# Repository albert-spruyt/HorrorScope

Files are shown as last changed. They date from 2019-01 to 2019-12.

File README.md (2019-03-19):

# HorrorScope / ScaCheapier

This repository contains all the firmware source, scripts and notebooks for the ScaCheapier workshop given at 35c3. 

We gave a talk about this work at Troopers 2019 NGI, with a different perspective. You can find the slides in the presentation directory.

## Abstract 
From: https://events.ccc.de/congress/2018/wiki/index.php/Session:ScaCheapier

Want to recover cryptographic keys by just looking at a chip's power usage, for the price of a few beers?

In this workshop we will show you how to break AES with just ~5 euro of equipment (plus your laptop and a bit of code).

Following in the tradition of the ChipWhisperer, but with even cheaper hardware, come and join the world of hardware side channel attacks. With a simple custom PCB (schematics provided), a cheap off-the-shelf MCU and a handful of supporting components, you'll have no problem stealing the keys. 

## Presentation

During the workshop we partially re-used a presentation created by Ilya Kizhvatov. The original slides can be found here:  
https://www.slideshare.net/phdays/ss-35302416  
A recording of Ilya himself giving the talk can be found here: https://vimeo.com/100108647  

If you saw our talk at Troopers, you missed out on all the theory; you can watch Ilya's presentation to get it!

## Code repository

The code in the repository, in particular the FI and Scope FW parts, should be considered PoC code. In fact, don't take anything here too seriously. Have fun!

The repository is organized as follows:

Scope   - Scope and Glitcher Firmware (firmware in lufa\*/Projects/HorrorScope  
Acq     - Python acquisition scripts including the Scope GUI  
FI      - Python FI scripts/ including plotting  
julia   - The julia jupyter notebook  
presentation - The presentation for the workshop (and the troopers talk) 
PCB     - PCB files  

#### Patched LUFA
The Scope folder contains an entire copy of LUFA http://fourwalledcubicle.com/LUFA.php  

To maximize the amount of SRAM available as sample memory LUFA has been patched to minimize the number and size of USB buffers.   

The patch has been applied in Drivers/USB/Core/XMEGA/Endpoint_XMEGA.h  

## Installation

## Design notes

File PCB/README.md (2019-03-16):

# HorrorScope PCB design

These are the kicad source files for our 'horrorscope' PCB. You can find gerbers in the 'horrorscope' directory.

(The 'breakout' directory contains gerbers for the breakout PCB we developed for debugging, which may be interesting too.)

Obviously .. we are not electrical engineers. Or good at PCB design. But it works! :)

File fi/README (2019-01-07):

#ONELINERS FTW
./parseLog.py log.log | sort -n | grep ' 4$' | awk {'print $3'} | sort -u | wc
-l # How many uniq faults do i have?
# extract faults for jean gray, you have to add the correct response to the
top
./parseLog.py log.log | sort -n | grep ' 4$' | awk {'print $3 " " $3'} | sort -u > JeanGrey-master/tracefile

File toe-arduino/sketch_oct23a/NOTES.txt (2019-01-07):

USES AESLIB from:
    https://github.com/DavyLandman/AESLib
Clone and move into ~/Arduino/libraries
And name the folder AESLib

Encrypt command has the format: 'a' + 16 bytes input data + '\n

Preparing the board:
    - Program board and verify functioning.
    - Cut next to the diode -> plug into USB -> power led shouldn't turn on
    - Cut next to the last pin of the USB chip
    - Solder diode (side with the cut) to pwr 5v (First put in a pin, solder to bottom of pin)

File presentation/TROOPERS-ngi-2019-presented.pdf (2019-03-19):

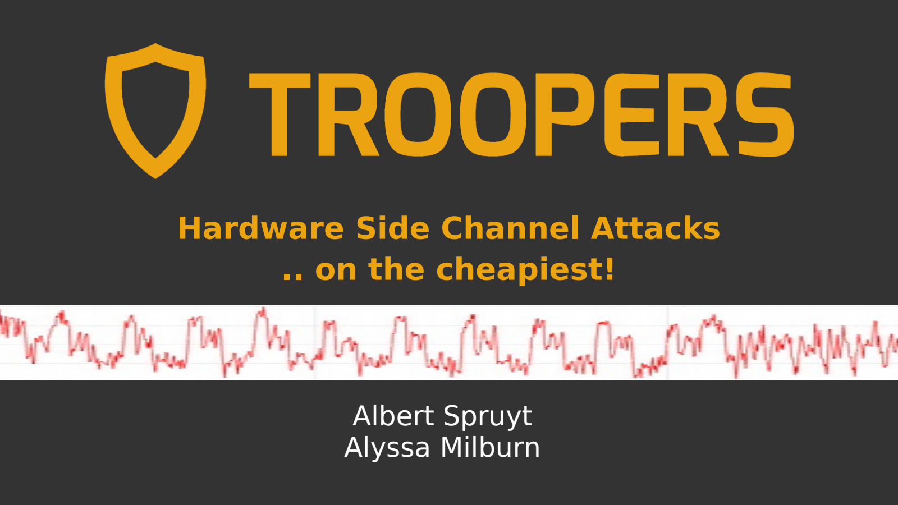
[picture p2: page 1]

Hardware Side Channel Attacks .. on the cheapiest!

Albert Spruyt
Alyssa Milburn

2

About Us

## Alyssa

PhD student

@noopwafel

## Albert

Unemployed

3

Today

## - Side Channel Analysis - (Cheap) Hardware - Demos! - A bit of Fault Injection

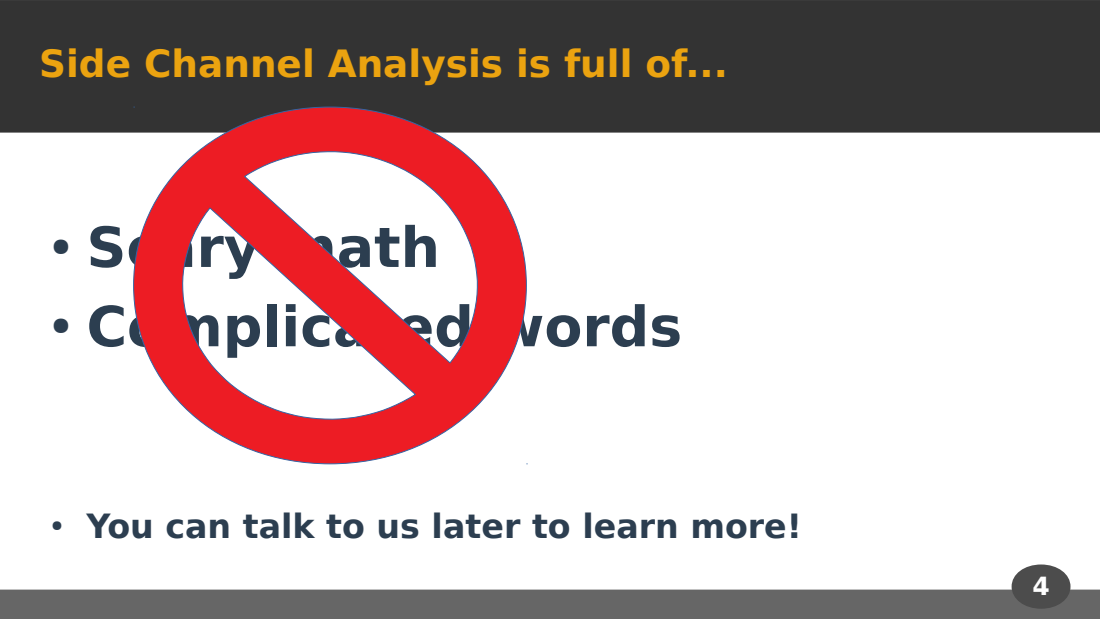
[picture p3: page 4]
● Scary math ● Complicated words

Side Channel Analysis is full of...

● You can talk to us later to learn more!

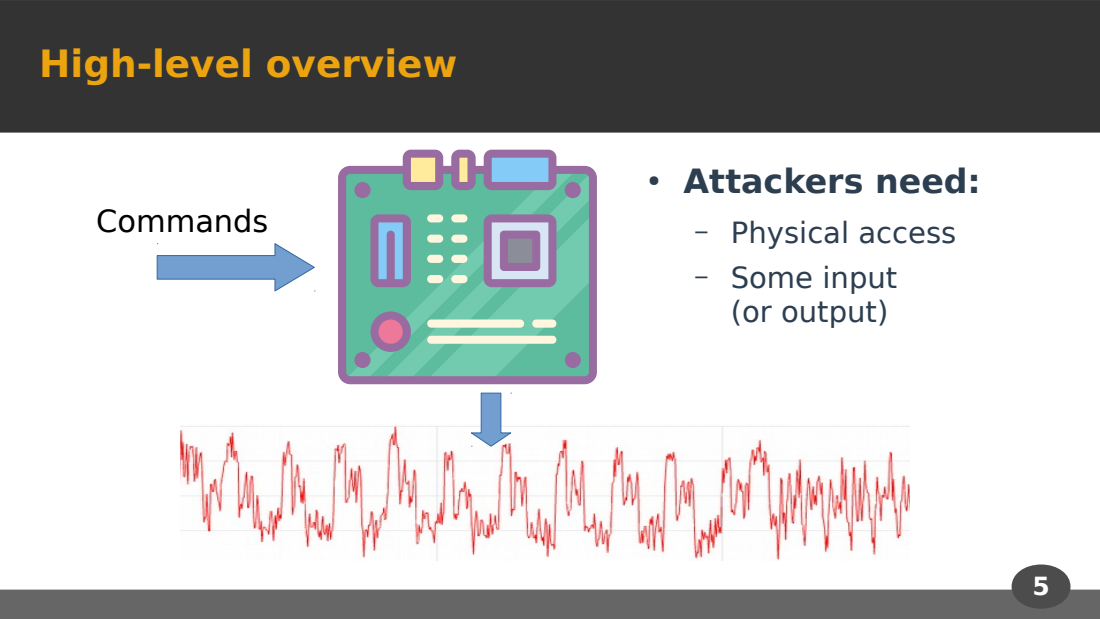
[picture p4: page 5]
Commands; ● Attackers need:; – Physical access – Some input (or output)

High-level overview

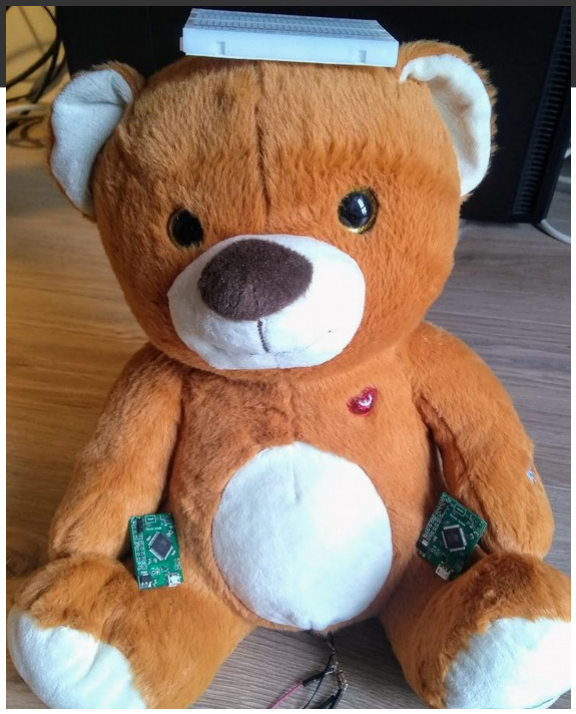
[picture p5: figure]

6

The context

- Smartcards
– credit cards, access cards, passports
- Secure microcontrollers
– crypto wallets, U2F/YubiKey
- Random IoT devices
– lightbulbs, ...

## Why care about side channels?

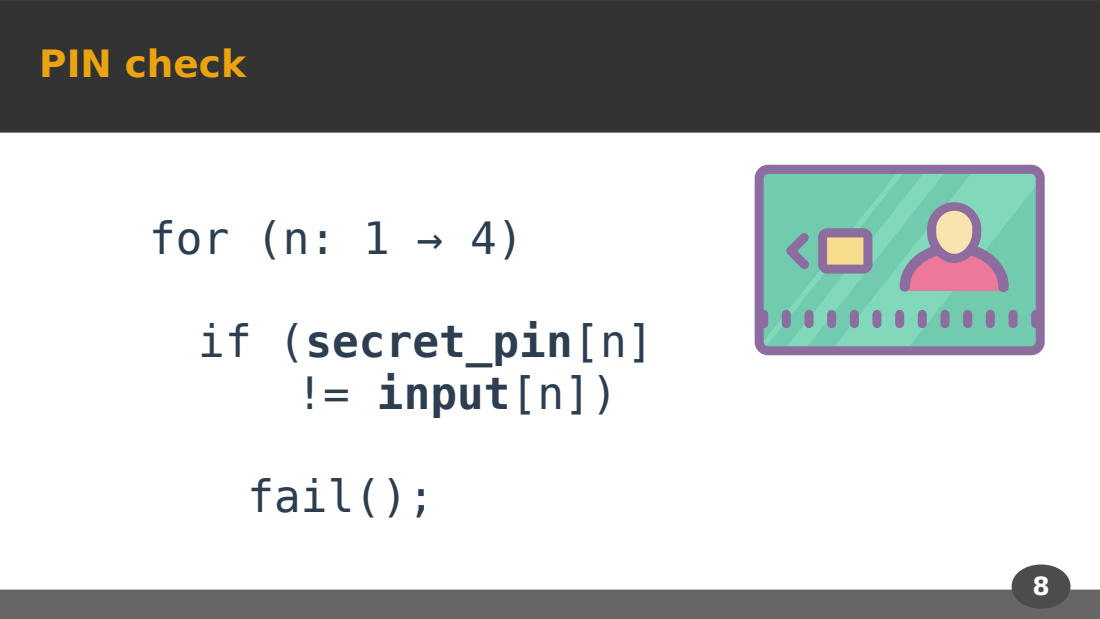
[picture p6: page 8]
PIN check; for (n: 1 → 4); if (secret_pin[n] != input[n]); fail();

9

PIN check

## if (secret_pin[n] != input[n])

fail();

10

PIN check

n=1

n=1 and n=2

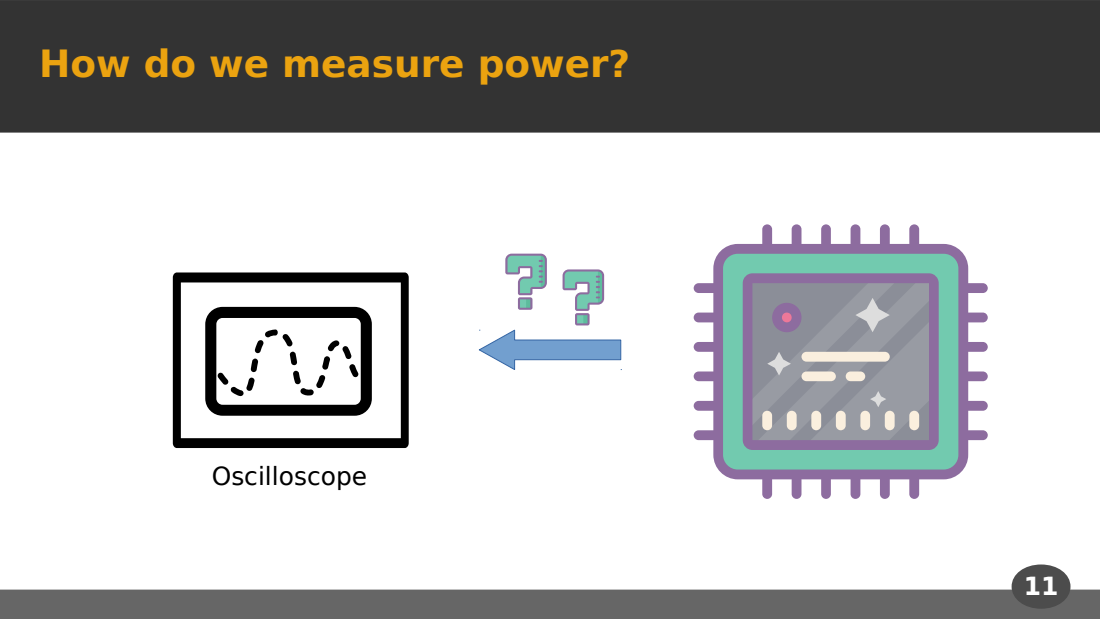
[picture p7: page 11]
Oscilloscope

How do we measure power?

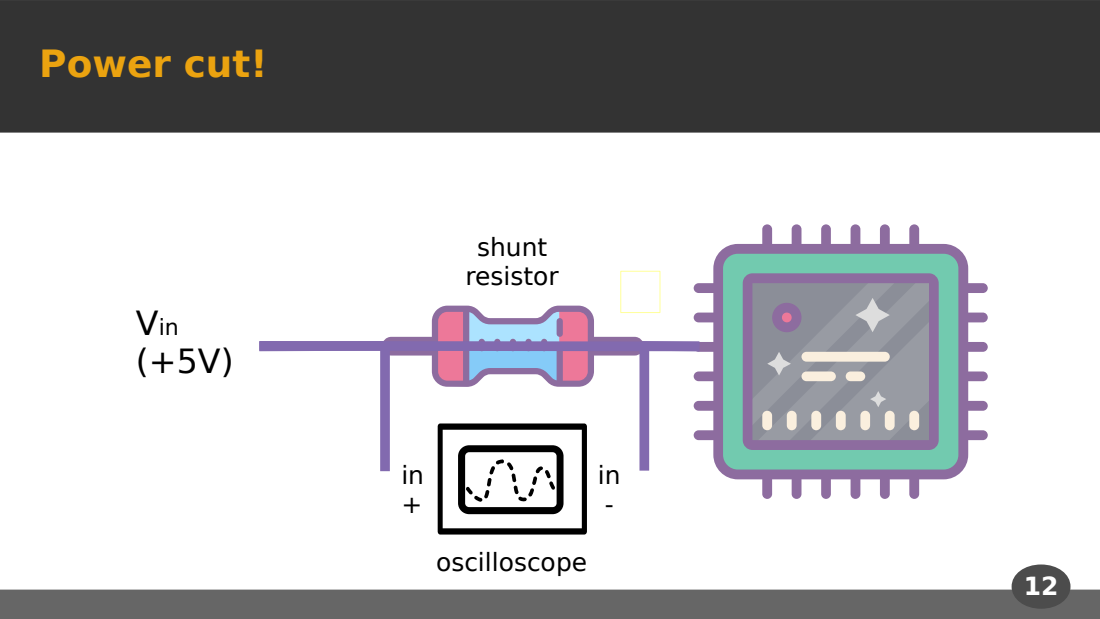
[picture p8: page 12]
Power cut!; Vin (+5V); shunt resistor; oscilloscope

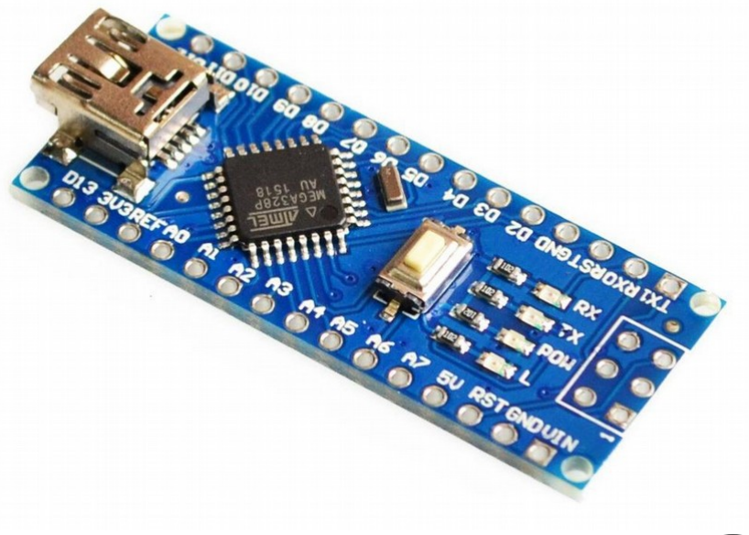
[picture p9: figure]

13

Today’s target

Arduino Nano

- 16 Mhz
- ~3-5 euro
- Not secure

14

Real power cuts

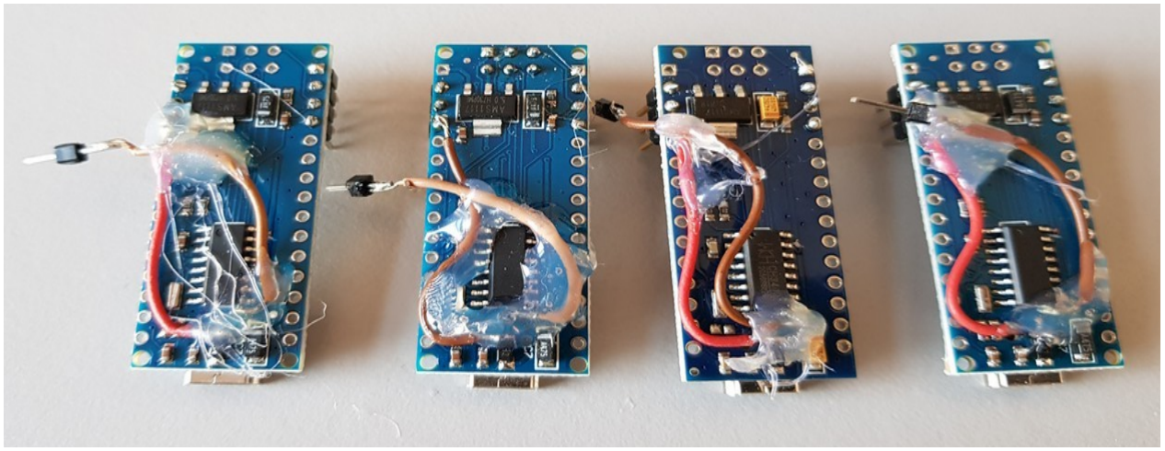
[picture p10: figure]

15

Real power cuts

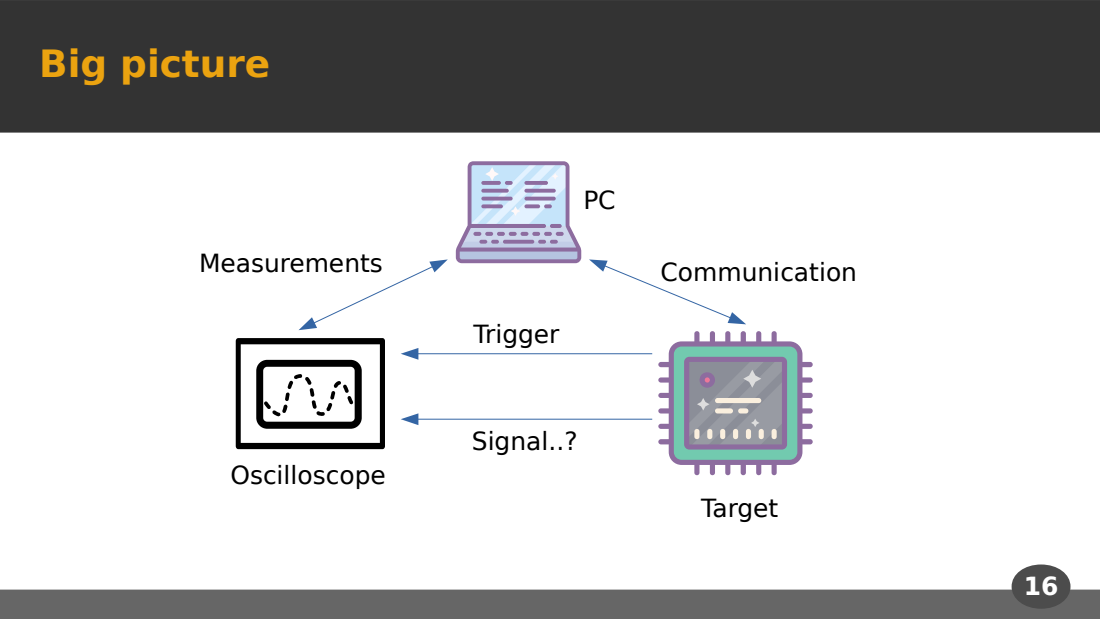
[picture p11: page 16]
Big picture; Measurements; Communication; Trigger; Signal..?; Oscilloscope; Target

17

DEMO

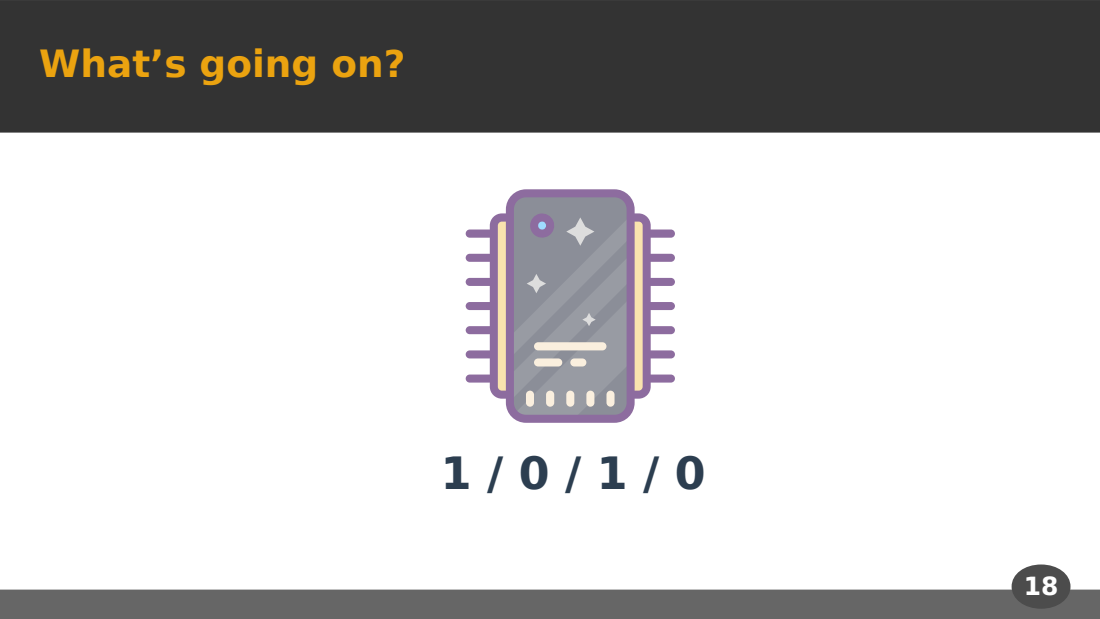
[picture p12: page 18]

What’s going on?

19

Hamming weight

0x00: 00000000
→ hamming weight 0

0xFF: 11111111
→ hamming weight 8

0x05: 00000101
→ hamming weight 2

0x11: 00010001
→ hamming weight 2

20

Leakage?

- Calculate with (random) bytes
- Take power traces

Can we match the Hamming Weight of the byte to the power traces?

21

Hamming weight

- Power profiles
based on different
data
- Averaged
- We can see the data
being processed!

Source: Side channel analysis, practice and a bit of theory. Ilya Kizhvatov

23

Keys

- We’re going to steal encryption keys – Everyone needs to have keys

24

Super secure encryption

- AES-128: unbroken and secure

Input

Initial ro

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
al R

o
u
n
d

Output

25

AES trace

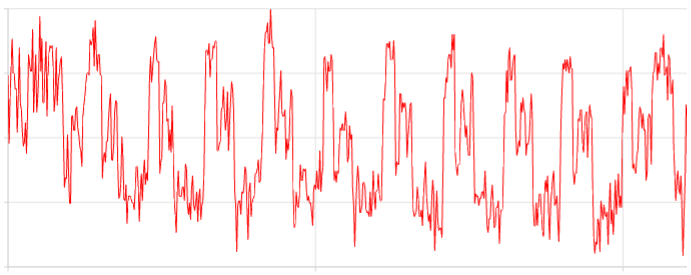
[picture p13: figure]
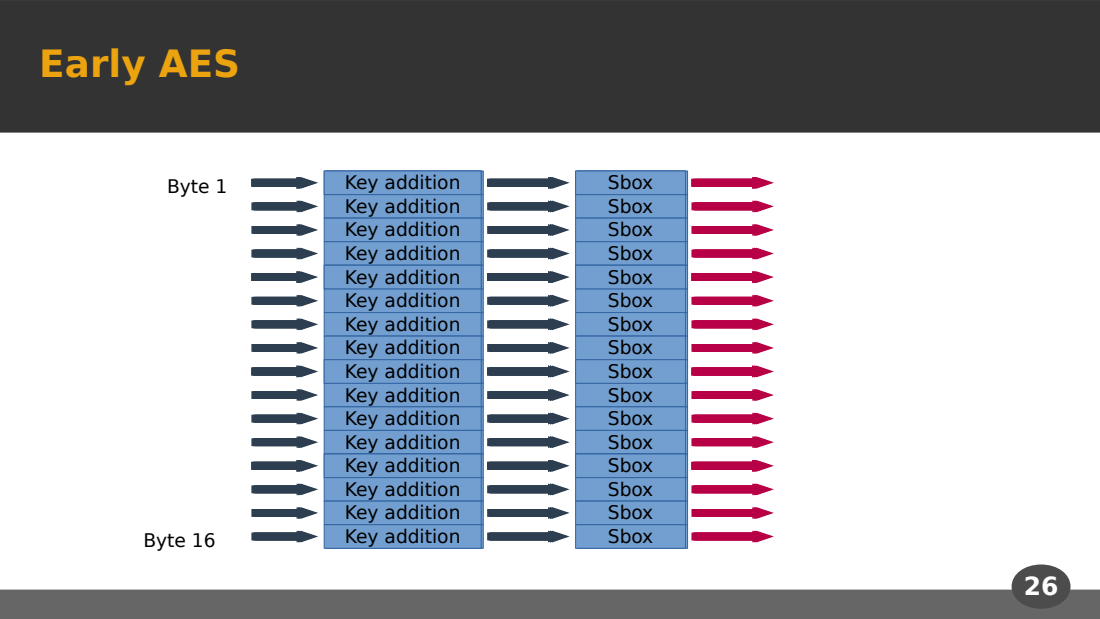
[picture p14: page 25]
Early AES; Key addition; Sbox; Byte 1; Byte 16

27

Single byte only

- We can look at each byte separately!

Key Addition; Input byte; Sbox; Key byte

28

Single byte only

- Only 256 possible key bytes – Try them all!

Key Addition; Input byte; Sbox; Key; byte; Hamming weight?

29

The master plan

- For every key guess:
– For each input:
- Calculate Hamming Weight after the S-box
- Compare that with the actual leakage
- Pick the guess with the best fit!

30

## Correlation Power Analysis

32

We’re lazy!

- Open source: JLSCA
– Does CPA for us
– Also supports fancier attacks – Runs fast on a cheap laptop

(Thanks Cees!)

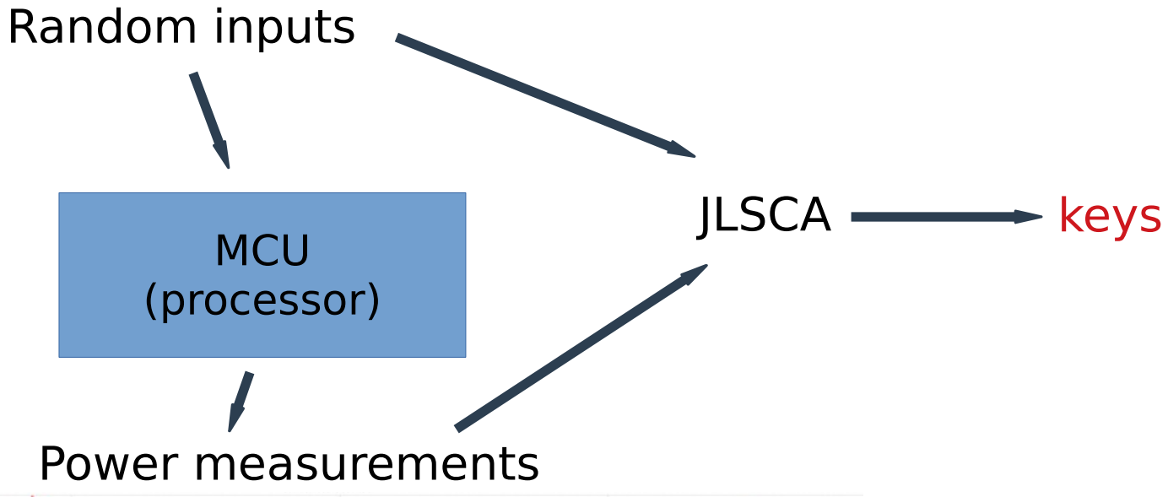
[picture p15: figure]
MCU (processor); Random inputs; Power measurements; JLSCA; keys

33

New plan

34

Oscilloscope?

35

Oscilloscopes

LeCroy WaveRunner | $17 000
PicoScope 3406D | $2 500
Rigol DS1054Z | $500

36

Previous Work

ChipWhisperer | $250
Hantek USB oscilloscope | $60
ChipWhisperer Nano..? | $50

ChipWhisperer
Nano

39

Solving our hardware woes

Let’s build an awesome, cheap scope!

Let’s hack something together!

40

What do we need?

- GPIO to trigger
- ADC to measure
- Memory to store measurements

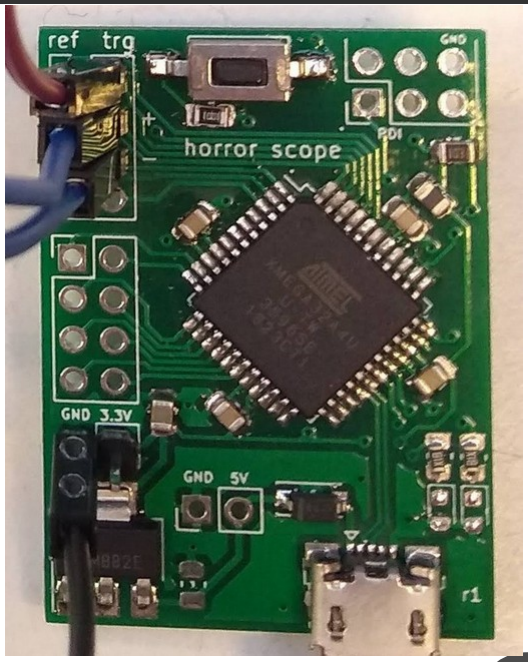
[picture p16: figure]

41

HorrorScope

Atmel XMEGA
– USB 2.0
– 12-bit ADC @2 MSPS

42

Bill of Materials (BOM)

~5 euro ex. VAT

Xmega: | 2.50eur
PCB: | 1eur

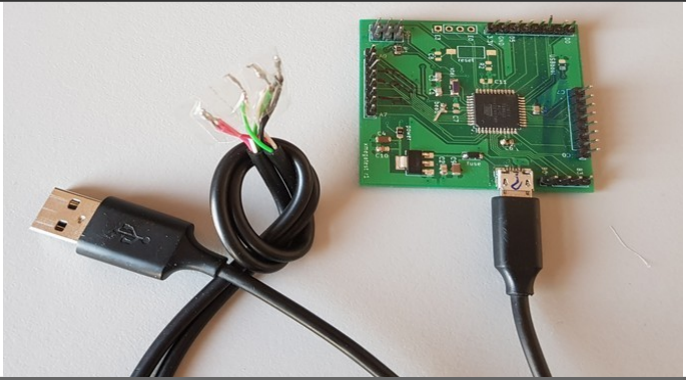
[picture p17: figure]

43

Funny story 1

44

More problems
Design considerations

Sampling below Nyqist frequency

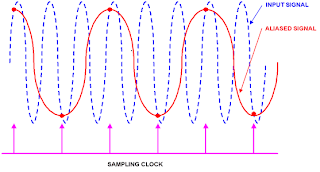
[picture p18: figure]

Source: http://blog.teledynelecroy.com/2013/06/back-to-basics-sampling-rate.html

Nano: | 16Mhz
Our ADC: | 2Mhz

45

Xmega datasheet

- Just a suggestion

46

More problems
Design considerations

No analog front-end

DC offset, resolution, noise, ... – AC coupling, use AREF

47

Funny story 2

Coding is hard

48

More traces!

100 traces averaged: A wild AES appears!

49

Acquisition

●

## So: let’s try it!

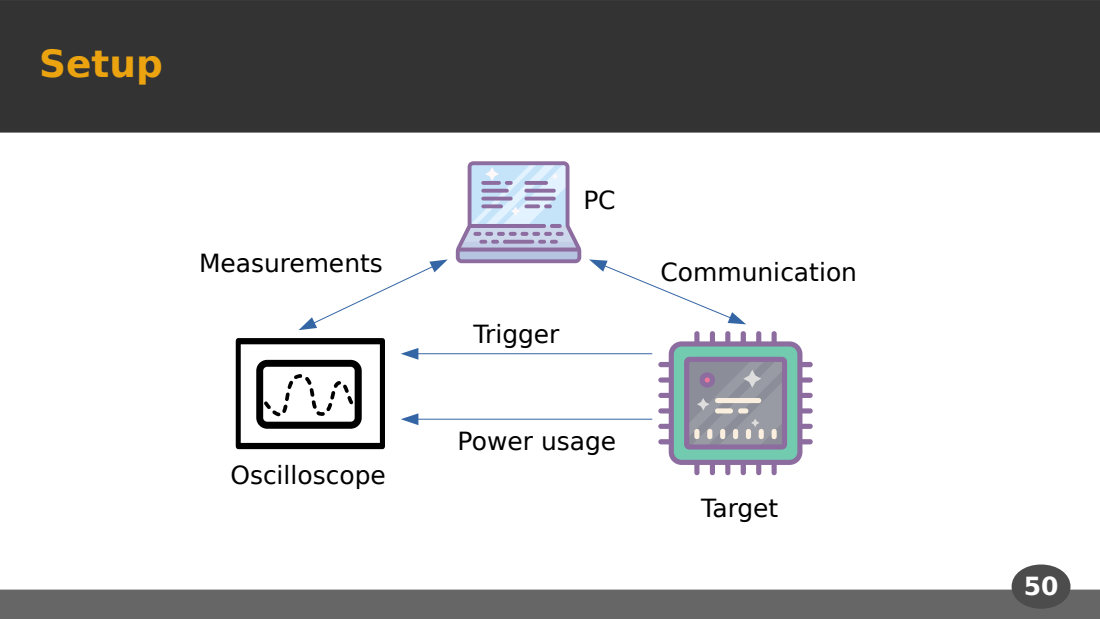
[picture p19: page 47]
Setup; Measurements; Communication; Trigger; Power usage; Oscilloscope; Target

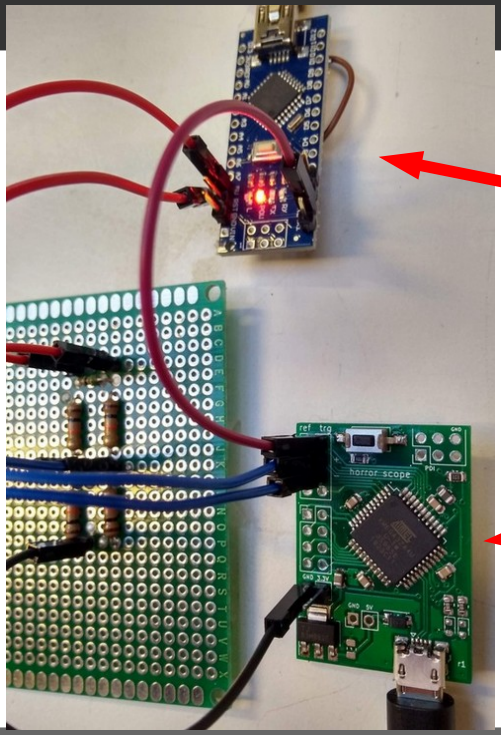
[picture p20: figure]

52

Real world setup

We have:
“Target”:
Arduino Nano + AES

“Oscilloscope”:
HorrorScope

53

Triggering

How does the scope know when to measure? – Not enough SRAM to sample all the time
– We need to sync the scope to the target

So, whats the last thing we control? – Sending the input

54

Triggering plan

- HorrorScope measuring procedure – Send command to Scope (arm)
– GPIO pin turns high
– Actually start measuring

– Connect Scope GPIO pin to RX on Nano

55

When to start measuring …

Time

Start

Send input
Arm scope

Send last input byte
Scope triggers
Target does AES
Save data +
power trace

56

Collect traces...

We need a lot of traces
– Make sure the first/or last round is in view – Select a high Sample speed
- Ensure there’s a margin before/after the round

57

Take Traces

- AES: initial round, 9 rounds, a final round

58

Acquiring Traces …

…. Here’s one we made earlier

59

Traces are bad

- Why are they bad?

60

What’s wrong?

- Misalignment

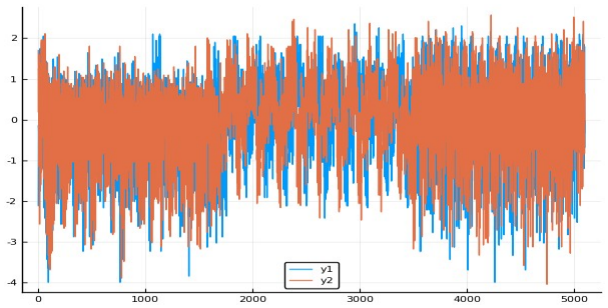
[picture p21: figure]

61

Signal spread

Source: Side channel analysis, practice and a bit of theory. Ilya Kizhvatov

62

Aligned

Aligned Not aligned!

Thank you JLSCA!

63

Why is alignment important?

Before | after

64

Let’s get keys

- DEMO
– Jupyter notebook

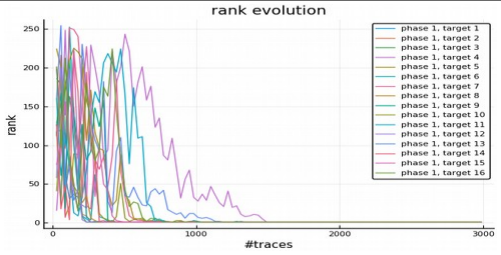
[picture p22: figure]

66

Comparing the scopes

Vds1022 ($70):
~1.5k traces

HorrorScope:

~30k traces

67

Funny Story 3

- How many mistakes can we make before it doesnt work?
- Silkscreen-Off-By-One

68

Funny story 3

- People told us the Xmega ADC was bad

69

Funny story 3

- 1000 averaged, no alignment

70

Strength in numbers

- Side Channel Attacks require overcoming the noise
- Noise can be reduced through taking more traces, but not in every case

71

Fault Injection

HorrorScope can sort of power the Nano

- The Nano wants 5v
- Xmega GPIO pins provide 3.2v

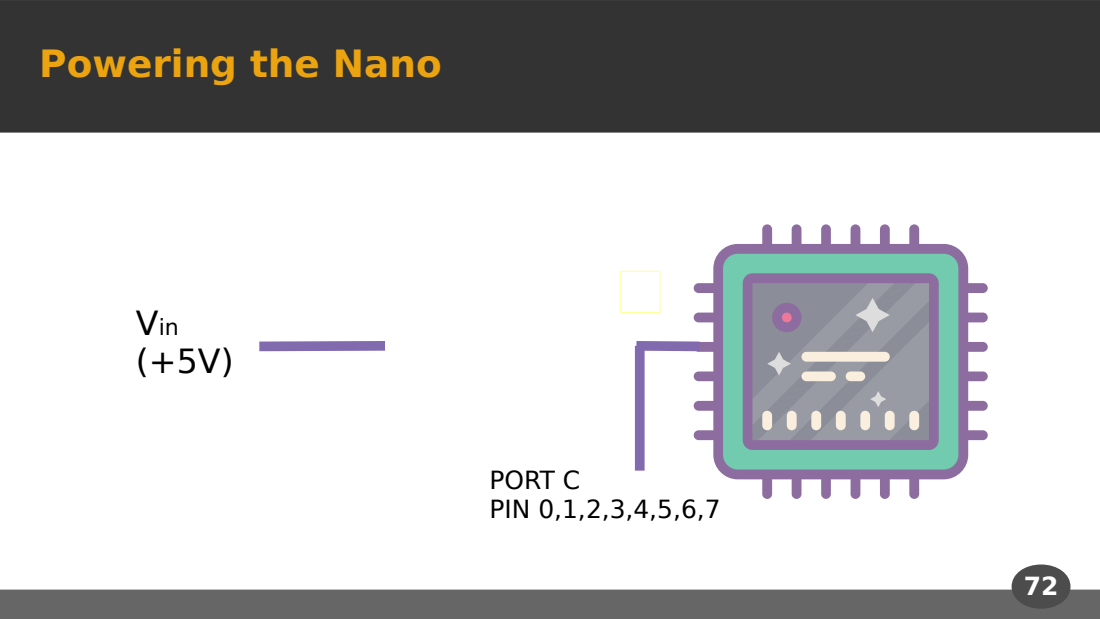
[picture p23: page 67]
Vin (+5V); PORT C PIN 0,1,2,3,4,5,6,7

Powering the Nano

73

Ok faults, now what?

- Perform Fault Injection and Differential Fault Analysis
- Inject faults into AES and recover the key

74

What can you do about it?

- Threat model
– Do you need to resist physical attacks? Best defense: make sure it doesn’t matter!
- Basic steps
– Use hardware with built-in countermeasures .. and check it with a (Horror)scope :)
(or a ChipWhisperer)!

75

Conclusion

- Hardware attacks are cheaper than we thought
- Side Channel Analysis is something you can do at home – and you should try it

76

Special Thanks

- Cees-Bart ‘ceesb’ Breunesse – https://github.com/Riscure/Jlsca
- Rafa Boix Carpi
– For saying it can’t be done
- Ilya Kizhvatov
– Letting us steal his pictures
- Workshop attendees
– For their feedback and love

77

Homework

https://github.com/albert-spruyt/HorrorScope/

Provided: power traces and Jlsca notebook. You should now be able to get the key!

(Also in the repo: schematics/source/etc) .. we’re hoping for a port to the STM32 – SCA for $2?

78

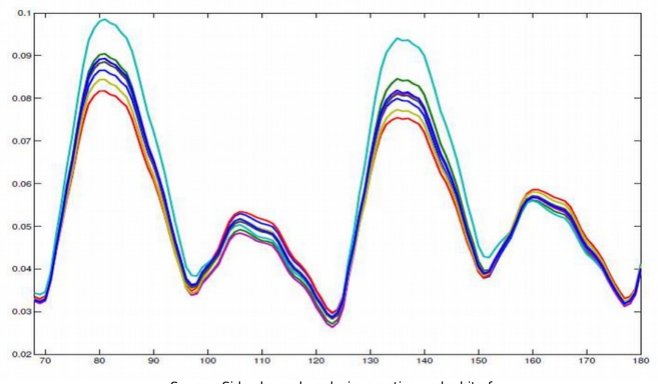
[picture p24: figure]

79

Hamming weight

- Power profiles
based on different
data
- Averaged
- We can see the data
being processed!

Source: Side channel analysis, practice and a bit of theory. Ilya Kizhvatov

80

Power cut: easy?

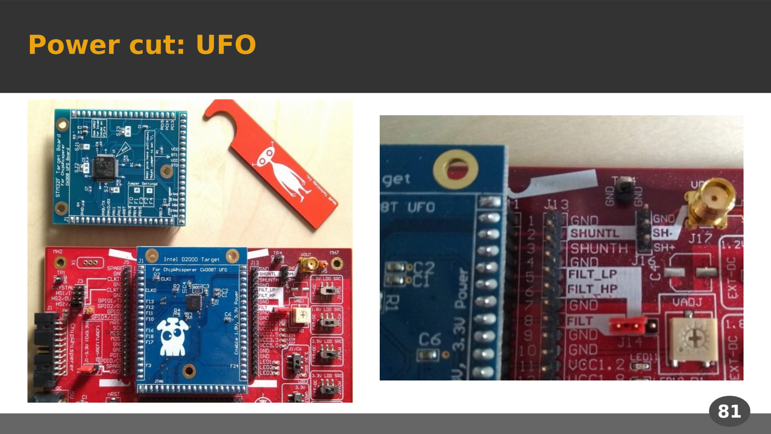
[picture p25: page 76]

81

Power cut: UFO

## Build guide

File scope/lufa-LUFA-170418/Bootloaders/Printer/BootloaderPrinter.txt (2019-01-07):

/** \file
 *
 *  This file contains special DoxyGen information for the generation of the main page and other special
 *  documentation pages. It is not a project source file.
 */

/** \mainpage Printer Class USB AVR Bootloader
 *
 *  \section Sec_Compat Demo Compatibility:
 *
 *  The following list indicates what microcontrollers are compatible with this demo.
 *
 *  \li Series 7 USB AVRs (AT90USBxxx7)
 *  \li Series 6 USB AVRs (AT90USBxxx6)
 *  \li Series 4 USB AVRs (ATMEGAxxU4)
 *  \li Series 2 USB AVRs (AT90USBxx2, ATMEGAxxU2)
 *
 *  \section Sec_Info USB Information:
 *
 *  The following table gives a rundown of the USB utilization of this demo.
 *
 *  <table>
 *   <tr>
 *    <td><b>USB Mode:</b></td>
 *    <td>Device</td>
 *   </tr>
 *   <tr>
 *    <td><b>USB Class:</b></td>
 *    <td>Printer Class</td>
 *   </tr>
 *   <tr>
 *    <td><b>USB Subclass:</b></td>
 *    <td>Printer Subclass</td>
 *   </tr>
 *   <tr>
 *    <td><b>Relevant Standards:</b></td>
 *    <td>USBIF Printer Class Standard</td>
 *   </tr>
 *   <tr>
 *    <td><b>Supported USB Speeds:</b></td>
 *    <td>Full Speed Mode</td>
 *   </tr>
 *  </table>
 *
 *  \section Sec_Description Project Description:
 *
 *  This bootloader enumerates to the host as a Generic Text Only Printer device, capable of reading and parsing
 *  "printed" plain-text Intel HEX files to load firmware onto the AVR.
 *
 *  Out of the box this bootloader builds for the AT90USB1287 with an 8KB bootloader section size, and will fit
 *  into 4KB of bootloader space. If you wish to alter this size and/or change the AVR model, you will need to
 *  edit the MCU, FLASH_SIZE_KB and BOOT_SECTION_SIZE_KB values in the accompanying makefile.
 *
 *  When the bootloader is running, the board's LED(s) will flash at regular intervals to distinguish the
 *  bootloader from the normal user application.
 *
 *  \section Sec_Running Running the Bootloader
 *
 *  On the USB AVR8 devices, setting the \c HWBE device fuse will cause the bootloader to run if the \c HWB pin of
 *  the AVR is grounded when the device is reset.
 *
 *  The are two behaviours of this bootloader, depending on the device's fuses:
 *
 *  <b>If the device's BOOTRST fuse is set</b>, the bootloader will run any time the system is reset from
 *  the external reset pin, unless no valid user application has been loaded. To initiate the bootloader, the
 *  device's external reset pin should be grounded momentarily.
 *
 *  <b>If the device's BOOTRST fuse is not set</b>, the bootloader will run only if initiated via a software
 *  jump, or if the \c HWB pin was low during the last device reset (if the \c HWBE fuse is set).
 *
 *  For board specific exceptions to the above, see below.
 *
 *  \subsection SSec_XPLAIN Atmel Xplain Board
 *  Ground the USB AVR JTAG's \c TCK pin to ground when powering on the board to start the bootloader. This assumes the
 *  \c HWBE fuse is cleared and the \c BOOTRST fuse is set as the HWBE pin is not user accessible on this board.
 *
 *  \subsection SSec_Leonardo Arduino Leonardo Board
 *  Ground \c IO13 when powering the board to start the bootloader. This assumes the \c HWBE fuse is cleared and the
 *  \c BOOTRST fuse is set as the HWBE pin is not user accessible on this board.
 *
 *  \section Sec_Installation Driver Installation
 *
 *  This bootloader uses the Generic Text-Only printer drivers inbuilt into all modern operating systems, thus no
 *  additional drivers need to be supplied for correct operation.
 *
 *  \section Sec_HostApp Host Controller Application
 *
 *  This bootloader is compatible with Notepad under Windows, and the command line \c lpr utility under Linux.
 *
 *  \subsection SSec_Notepad Notepad (Windows)
 *
 *  While most text applications under Windows will be compatible with the bootloader, the inbuilt Notepad utility
 *  is recommended as it will introduce minimal formatting changes to the output stream. To program with Notepad,
 *  open the target HEX file and print it to the Generic Text Only printer device the bootloader creates.
 *
 *  \subsection SSec_LPR LPR (Linux)
 *
 *  While the CUPS framework under Linux will enumerate the bootloader as a Generic Text-Only printer, many
 *  applications will refuse to print to the device due to the lack of rich formatting options available. As a result,
 *  under Linux HEX files must be printed via the low level \c lpr utility instead.
 *
 *  \code
 *  cat Mouse.hex | lpr
 *  \endcode
 *
 *  \section Sec_API User Application API
 *
 *  Several user application functions for FLASH and other special memory area manipulations are exposed by the bootloader,
 *  allowing the user application to call into the bootloader at runtime to read and write FLASH data.
 *
 *  By default, the bootloader API jump table is located 32 bytes from the end of the device's FLASH memory, and follows the
 *  following layout:
 *
 *  \code
 *  #define BOOTLOADER_API_TABLE_SIZE          32
 *  #define BOOTLOADER_API_TABLE_START         ((FLASHEND + 1UL) - BOOTLOADER_API_TABLE_SIZE)
 *  #define BOOTLOADER_API_CALL(Index)         (void*)((BOOTLOADER_API_TABLE_START + (Index * 2)) / 2)
 *
 *  void    (*BootloaderAPI_ErasePage)(uint32_t Address)               = BOOTLOADER_API_CALL(0);
 *  void    (*BootloaderAPI_WritePage)(uint32_t Address)               = BOOTLOADER_API_CALL(1);
 *  void    (*BootloaderAPI_FillWord)(uint32_t Address, uint16_t Word) = BOOTLOADER_API_CALL(2);
 *  uint8_t (*BootloaderAPI_ReadSignature)(uint16_t Address)           = BOOTLOADER_API_CALL(3);
 *  uint8_t (*BootloaderAPI_ReadFuse)(uint16_t Address)                = BOOTLOADER_API_CALL(4);
 *  uint8_t (*BootloaderAPI_ReadLock)(void)                            = BOOTLOADER_API_CALL(5);
 *  void    (*BootloaderAPI_WriteLock)(uint8_t LockBits)               = BOOTLOADER_API_CALL(6);
 *
 *  #define BOOTLOADER_MAGIC_SIGNATURE_START   (BOOTLOADER_API_TABLE_START + (BOOTLOADER_API_TABLE_SIZE - 2))
 *  #define BOOTLOADER_MAGIC_SIGNATURE         0xDCFB
 *
 *  #define BOOTLOADER_CLASS_SIGNATURE_START   (BOOTLOADER_API_TABLE_START + (BOOTLOADER_API_TABLE_SIZE - 4))
 *  #define BOOTLOADER_PRINTER_SIGNATURE       0xDF20
 *
 *  #define BOOTLOADER_ADDRESS_START           (BOOTLOADER_API_TABLE_START + (BOOTLOADER_API_TABLE_SIZE - 8))
 *  #define BOOTLOADER_ADDRESS_LENGTH          4
 *  \endcode
 *
 *  From the application the API support of the bootloader can be detected by reading the FLASH memory bytes located at address
 *  \c BOOTLOADER_MAGIC_SIGNATURE_START and comparing them to the value \c BOOTLOADER_MAGIC_SIGNATURE. The class of bootloader
 *  can be determined by reading the FLASH memory bytes located at address \c BOOTLOADER_CLASS_SIGNATURE_START and comparing them
 *  to the value \c BOOTLOADER_PRINTER_SIGNATURE. The start address of the bootloader can be retrieved by reading the bytes of FLASH
 *  memory starting from address \c BOOTLOADER_ADDRESS_START.
 *
 *  \subsection SSec_API_MemLayout Device Memory Map
 *  The following illustration indicates the final memory map of the device when loaded with the bootloader.
 *
 *  \verbatim
 *  +----------------------------+ 0x0000
 *  |                            |
 *  |                            |
 *  |                            |
 *  |                            |
 *  |                            |
 *  |                            |
 *  |                            |
 *  |                            |
 *  |      User Application      |
 *  |                            |
 *  |                            |
 *  |                            |
 *  |                            |
 *  |                            |
 *  |                            |
 *  |                            |
 *  +----------------------------+ FLASHEND - BOOT_SECTION_SIZE
 *  |                            |
 *  |   Bootloader Application   |
 *  | (Not User App. Accessible) |
 *  |                            |
 *  +----------------------------+ FLASHEND - 96
 *  |   API Table Trampolines    |
 *  | (Not User App. Accessible) |
 *  +----------------------------+ FLASHEND - 32
 *  |    Bootloader API Table    |
 *  |   (User App. Accessible)   |
 *  +----------------------------+ FLASHEND - 8
 *  |   Bootloader ID Constants  |
 *  |   (User App. Accessible)   |
 *  +----------------------------+ FLASHEND
 *  \endverbatim
 *
 *
 *  \section Sec_KnownIssues Known Issues:
 *
 *  \par On Linux machines, new firmware fails to be sent to the device via CUPS.
 *  Only a limited subset of normal printer functionality is exposed via the
 *  bootloader, causing CUPS to reject print requests from applications that
 *  are unable to handle true plain-text printing. For best results, the low
 *  level \c lpr command should be used to print new firmware to the bootloader.
 *
 *  \section Sec_Options Project Options
 *
 *  The following defines can be found in this demo, which can control the demo behaviour when defined, or changed in value.
 *
 *  <table>
 *   <tr>
 *    <td>
 *     None
 *    </td>
 *   </tr>
 *  </table>
 */

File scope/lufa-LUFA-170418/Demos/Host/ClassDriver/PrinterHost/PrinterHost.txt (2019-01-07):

/** \file
 *
 *  This file contains special DoxyGen information for the generation of the main page and other special
 *  documentation pages. It is not a project source file.
 */

/** \mainpage Printer Host Demo
 *
 *  \section Sec_Compat Demo Compatibility:
 *
 *  The following list indicates what microcontrollers are compatible with this demo.
 *
 *  \li Series 7 USB AVRs (AT90USBxxx7)
 *
 *  \section Sec_Info USB Information:
 *
 *  The following table gives a rundown of the USB utilization of this demo.
 *
 *  <table>
 *   <tr>
 *    <td><b>USB Mode:</b></td>
 *    <td>Host</td>
 *   </tr>
 *   <tr>
 *    <td><b>USB Class:</b></td>
 *    <td>Printer Device</td>
 *   </tr>
 *   <tr>
 *    <td><b>USB Subclass:</b></td>
 *    <td>Bidirectional Protocol</td>
 *   </tr>
 *   <tr>
 *    <td><b>Relevant Standards:</b></td>
 *    <td>USBIF Printer Class Specification \n
 *        PCL Language Specification</td>
 *   </tr>
 *   <tr>
 *    <td><b>Supported USB Speeds:</b></td>
 *    <td>Low Speed Mode \n
 *        Full Speed Mode</td>
 *   </tr>
 *  </table>
 *
 *  \section Sec_Description Project Description:
 *
 *  Printer host demonstration application. This gives a simple reference
 *  application for implementing a USB Printer host, for USB printers using
 *  the bidirectional data encapsulation protocol and PCL language.
 *
 *  Upon connection of a compatible printer, the printer's device ID is sent
 *  to the AVR's serial port, and a simple test page is printed using the PCL
 *  printer language.
 *
 *  \section Sec_Options Project Options
 *
 *  The following defines can be found in this demo, which can control the demo behaviour when defined, or changed in value.
 *
 *  <table>
 *   <tr>
 *    <td>
 *     None
 *    </td>
 *   </tr>
 *  </table>
 */

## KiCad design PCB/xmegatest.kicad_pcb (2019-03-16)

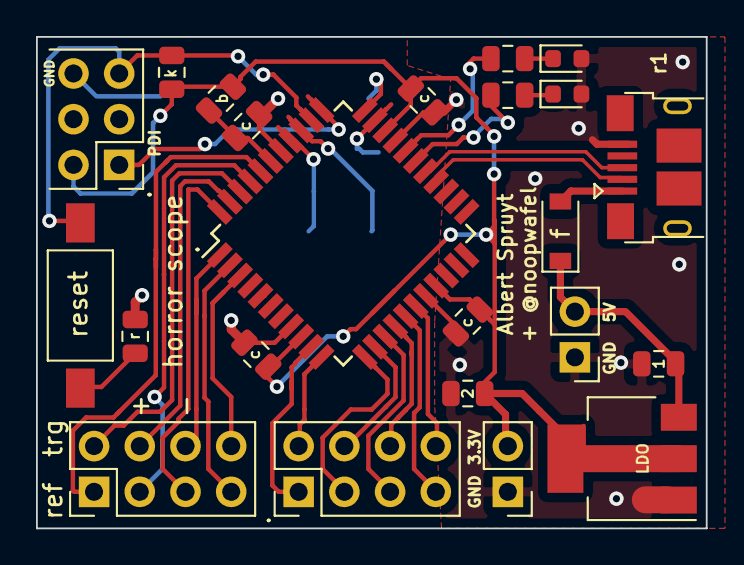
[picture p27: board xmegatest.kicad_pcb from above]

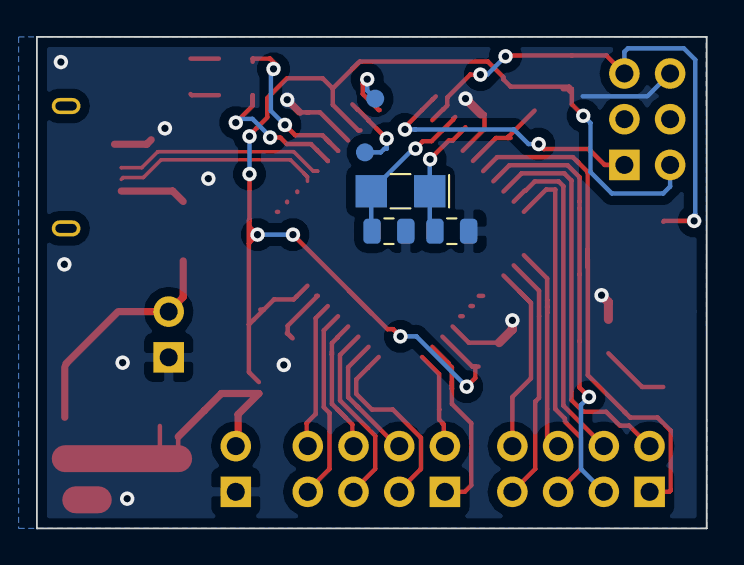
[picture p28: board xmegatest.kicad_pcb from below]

Board: 2 copper layers, 37.2 x 27.3 mm, 25 parts (3 on the bottom side), 30 nets.

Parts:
C1, C3: C_Small; C_0805_2012Metric
C2, C4: 100uF; C_0805_2012Metric
C5, C6, C7, C11: 100nF; C_0805_2012Metric
F1: fuse; D_SOD-123
J1: AVR-PDI-6; PinHeader_2x03_P2.54mm_Vertical_noline
J2: USB_B_Micro; USB_Micro-B_Amphenol_hax
J5, J7: Conn_01x08_Female; PinHeader_2x04_P2.54mm_Vertical
JP1: 0; PinHeader_1x02_P2.54mm_Vertical
L1: Ferrite_Bead_Small; L_0805_2012Metric
LED1, LED2: LED_0603_1608Metric
R1: 10k; R_0805_2012Metric
R2: 0; R_0805_2012Metric
RLED1, RLED2: R_0805_2012Metric
SW1: SW_Push; SW_SPST_FSMSM
U1: LM1117-3.3; SOT-223-3_TabPin2
U2: ATxmega128A4U-AU; TQFP-44_10x10mm_P0.8mm
Y1: 32.768hz; Crystal_SMD_MicroCrystal_CC7V-T1A-2Pin_3.2x1.5mm_HandSolder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

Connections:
+3V3: C4.1, C5.2, C6.2, C11.2, J1.2, JP1.2, L1.2, R1.1, U1.2, U2.9, U2.19, U2.31
+5V: C2.1, F1.1, U1.3
/PDI_DATA: J1.1, U2.34
/RESET: J1.5, R1.2, SW1.2, U2.35
/USBD+: J2.3, U2.27
/USBD-: J2.2, U2.26
/XTAL1: C1.1, U2.37, Y1.1
/XTAL2: C3.1, U2.36, Y1.2
GND: C1.2, C2.2, C3.2, C4.2, C5.1, C6.1, C7.1, C11.1, J1.6, J2.5, JP1.1, LED1.2, LED2.2, R2.1, U1.1, U2.8, U2.18, U2.30, U2.38
unnamed: C7.2, L1.1, U2.39
unnamed: F1.2, J2.1
unnamed: J5.1, U2.40
unnamed: J5.3, U2.41
unnamed: J5.2, U2.42
unnamed: J5.4, U2.43
unnamed: J5.5, U2.44
unnamed: J5.6, U2.1
unnamed: J5.7, U2.2
unnamed: J5.8, U2.3
unnamed: J7.1, U2.10
unnamed: J7.2, U2.11
unnamed: J7.3, U2.12
unnamed: J7.4, U2.13
unnamed: J7.5, U2.14
unnamed: J7.6, U2.15
unnamed: J7.7, U2.16
unnamed: J7.8, U2.17
unnamed: R2.2, SW1.1
unnamed: RLED2.1, U2.28
unnamed: RLED1.1, U2.29

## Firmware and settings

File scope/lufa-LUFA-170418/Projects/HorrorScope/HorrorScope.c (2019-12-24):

#include <string.h>
#include <avr/cpufunc.h>
#include <avr/interrupt.h>
#include <avr/io.h>
#include <avr/sleep.h>
#include "adc.h"
#include "trigger.h"
#include "dmaadc.h"
#include "hires_glitch.h"
#include "usartx.h"
#include <avr/signature.h>
#include "usb_serial.h"
#include <LUFA/Drivers/USB/USB.h>
#define CLKSYS_IsReady( _oscSel ) ( OSC.STATUS & (_oscSel) )
#define CLKSYS_Enable( _oscSel ) ( OSC.CTRL |= (_oscSel) )
extern USB_ClassInfo_CDC_Device_t VirtualSerial_CDC_Interface;
static uint8_t scopeBuf[1024 * 3 + 512] ;

int main(void) {
    uint32_t timeout=40000;
    uint16_t delay=0;
    uint16_t numberOfSamples = sizeof(scopeBuf);
    uint8_t glitch_length = 0;
    uint8_t bits12 = 1;
    uint8_t pulses=1;

    memset(scopeBuf,'U',sizeof(scopeBuf));

	//Clocks
	 OSC_CTRL |= OSC_RC32MEN_bm | OSC_XOSCEN_bm;    // Enabled the internal 32MHz oscillator
	 while ((OSC_STATUS & OSC_RC32MRDY_bm) == 0)
	      ;  // wait for oscillator to finish starting.
	 PROTECTED_WRITE(CLK_CTRL, CLK_SCLKSEL_RC32M_gc);  // select the 32MHz oscillator as system clock.

    //OSC_DFLLCTRL |= OSC_RC2MCREF_bm;

    //For external Crystal
    //OSC_DFLLCTRL |= OSC_RC32MCREF_XOSC32K_gc;
    OSC_DFLLCTRL |= OSC_RC32MCREF_USBSOF_gc;

    DFLLRC2M.CTRL |= DFLL_ENABLE_bm;
    DFLLRC32M.CTRL |= DFLL_ENABLE_bm;

    OSC.PLLCTRL = (OSC_PLLSRC_RC32M_gc | (6 << OSC_PLLFAC_gp));
    OSC_CTRL |= OSC_PLLEN_bm;

    while( (OSC_STATUS & OSC_PLLRDY_bm) == 0 ); //Wait for PLL to stabilize

    CLKSYS_Enable(OSC_PLLEN_bm | OSC_RC32MEN_bm);
    while (CLKSYS_IsReady(OSC_PLLRDY_bm) == 0);

    //The peripheral clock will be fed of the CPU clock, other peripherals will need to be pre-scaled accordingly
	CLK.PSCTRL = CLK_PSADIV0_bm; 
    PMIC.CTRL |= PMIC_HILVLEN_bm|PMIC_MEDLVLEN_bm;
    sei();
    set_sleep_mode(SLEEP_MODE_IDLE);

	//serial
	USART_CTX_t *serial = usart_c0_ctx;
	usart_init(serial);

	adc_init(bits12);
	dmaadc_init(bits12);
	//GPIO TRIGGER
    trigger_init();

	//GPIO POWER
	PORTC.DIRSET = 0xff;
    PORTC.OUT=0xff;
    TCC2.CTRLC=0xff;

    USB_serial_init();

    hires_init();
    hires_set_period(0xff);
	usart_put_string_P(serial,"Welcome to the HorrorScope\r\n");

    //Clock-gate unused stuff, hope for less noise.
    //FROM: http://ww1.microchip.com/downloads/en/DeviceDoc/doc8267.pdf
    //TODO: We should first stop all of these devices, are they default off?
    //TODO: We should check if we cant turn off any more, i.e. uarts c and d, and their timers?
    PR.PRGEN|= PR_AES_bm | PR_EBI_bm | PR_RTC_bm;
    PR.PRPA |= PR_DAC_bm | PR_AC_bm;       //ADC channel
    PR.PRPB |= PR_DAC_bm | PR_AC_bm | PR_ADC_bm;
    PR.PRPC |= PR_TWI_bm | PR_SPI_bm;    //Glitch channels (maybe uart)
    PR.PRPD |= PR_TWI_bm | PR_SPI_bm;    //maybe uart 
    PR.PRPE |= PR_TWI_bm | PR_SPI_bm | PR_USART0_bm | PR_USART1_bm | PR_TC0_bm | PR_TC1_bm;
    PR.PRPF |= PR_TWI_bm | PR_SPI_bm | PR_USART0_bm | PR_USART1_bm | PR_TC0_bm | PR_TC1_bm;
    //ccp_write_io((void*)&NVM.CTRLB, NVM_EPRM_bm); //We don't use EEPROM

	while(1){
        char command = USB_serial_get_char();
		switch(command){
            case 'T':
			case 't':
                USB_serial_put_char('T');
				break;
			case 'd':{ //DMA ARM
                memset(scopeBuf,0,sizeof(scopeBuf));
                USB_serial_put_char('r');

                uint8_t timedOut = trigger_wait(timeout,delay);

				dmaadc_read_buf_ch0(scopeBuf,numberOfSamples,bits12);
                USB_serial_put_char(timedOut?'e':'d');
				break;
            }
			case 's'://Sample fetch
                USB_serial_put_buf(scopeBuf,numberOfSamples);
				break;
			case 'n':{ //Set number of samples
                uint16_t temp = USB_serial_get_short();
				
				if( temp > sizeof(scopeBuf)) {
                    USB_serial_put_string_P("Buffer too big\r\n");
                    break;
                }

                numberOfSamples = temp;
                USB_serial_put_char('d');
				break;
			}
			case 'g'://Set gain
				adc_ch_gain(&(ADCA.CH0), USB_serial_get_char() << 2 );
                USB_serial_put_char('d');
				break;
			case 'c'://Set clock divider ( values: 0-7 )
				adc_prescaler(USB_serial_get_char() & 0x7 );
                USB_serial_put_char('d');
				break;
			case 'b'://Set bias...
				adc_calibrate(USB_serial_get_short()); 
                USB_serial_put_char('d');
				break;
			case 'f':{  //Fault (g is taken)
                USB_serial_put_char('r');

                uint8_t timedOut = trigger_wait(timeout,delay);
                //glitch(0,glitch_length,0xff);

                USB_serial_put_char(timedOut?'d':'e');//d = done;e=error/timeout
				break;
			}
            case '8'://Definition of Bits12? fetch 2bytes: fetch the LSB
                bits12 = USB_serial_get_char() & 1;
                //adc_resolution(ADC_RESOLUTION_12BIT_gc);
                dmaadc_init(bits12);
                trigger_init(); //As the dmaadc reconfigures the DMA controller
                USB_serial_put_char('d');
                break;
            case 'h':{
                //Initialization
                hires_set_counter(0x00);
                hires_set_compare(0xff-((uint8_t)glitch_length));

                //Say we did the initialization
                USB_serial_put_char('r');

                uint8_t timedOut = trigger_wait(timeout,delay);
                //Do the glitch
                for(int i=0;i < pulses;i++){
                    hires_set_counter(0x00);
                    hires_glitch();
                }
                
                USB_serial_put_char(timedOut?'e':'d');
                break;
            }
			case 'w': //Wait (d is taken)
				delay = USB_serial_get_short();
                USB_serial_put_char('d');
				break;
			case 'l': //glitch Length
				glitch_length = USB_serial_get_short();
                USB_serial_put_char('d');
				break;
			case 'e': //Exit timeout t was taken	
				timeout = USB_serial_get_short();
                USB_serial_put_char('d');
				break;
			case 'p': //Exit timeout t was taken	
				pulses = USB_serial_get_char();
                USB_serial_put_char('d');
				break;
			case 'x': //Turn off
				PORTC.OUTCLR = 0xff;
                TCC2.CTRLC = 0x00; //This is used when TCC2 override is enabled
                USB_serial_put_char('d');
				break;
			case 'y': //turn on
				PORTC.OUTSET = 0xff;
                TCC2.CTRLC = 0xff;
                USB_serial_put_char('d');
				break;
			default:
                USB_serial_put_string_P("Invalid command:");
				USB_serial_put_char(command);
                USB_serial_put_string_P("\r\n");
				break;
		}
	}
}

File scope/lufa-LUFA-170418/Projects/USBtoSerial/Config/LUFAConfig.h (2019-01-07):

#define FIXED_CONTROL_ENDPOINT_SIZE      8
#define DEVICE_STATE_AS_GPIOR            0
#define FIXED_NUM_CONFIGURATIONS         1
/*
             LUFA Library
     Copyright (C) Dean Camera, 2017.

  dean [at] fourwalledcubicle [dot] com
           www.lufa-lib.org
*/

/*
  Copyright 2017  Dean Camera (dean [at] fourwalledcubicle [dot] com)

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
  The author disclaims all warranties with regard to this
  software, including all implied warranties of merchantability
  and fitness.  In no event shall the author be liable for any
  special, indirect or consequential damages or any damages
  whatsoever resulting from loss of use, data or profits, whether
  in an action of contract, negligence or other tortious action,
  arising out of or in connection with the use or performance of
  this software.
*/

/** \file
 *  \brief LUFA Library Configuration Header File
 *
 *  This header file is used to configure LUFA's compile time options,
 *  as an alternative to the compile time constants supplied through
 *  a makefile.
 *
 *  For information on what each token does, refer to the LUFA
 *  manual section "Summary of Compile Tokens".
 */

#ifndef _LUFA_CONFIG_H_
#define _LUFA_CONFIG_H_

	#if (ARCH == ARCH_AVR8)

		/* Non-USB Related Configuration Tokens: */
//		#define DISABLE_TERMINAL_CODES

		/* USB Class Driver Related Tokens: */
//		#define HID_HOST_BOOT_PROTOCOL_ONLY
//		#define HID_STATETABLE_STACK_DEPTH       {Insert Value Here}
//		#define HID_USAGE_STACK_DEPTH            {Insert Value Here}
//		#define HID_MAX_COLLECTIONS              {Insert Value Here}
//		#define HID_MAX_REPORTITEMS              {Insert Value Here}
//		#define HID_MAX_REPORT_IDS               {Insert Value Here}
//		#define NO_CLASS_DRIVER_AUTOFLUSH

		/* General USB Driver Related Tokens: */
//		#define ORDERED_EP_CONFIG
		#define USE_STATIC_OPTIONS               (USB_DEVICE_OPT_FULLSPEED | USB_OPT_REG_ENABLED | USB_OPT_AUTO_PLL | USB_OPT_BUSEVENT_PRIMED;
		#define USB_DEVICE_ONLY
//		#define USB_HOST_ONLY
//		#define USB_STREAM_TIMEOUT_MS            {Insert Value Here}
//		#define NO_LIMITED_CONTROLLER_CONNECT
//		#define NO_SOF_EVENTS

		/* USB Device Mode Driver Related Tokens: */
//		#define USE_RAM_DESCRIPTORS
		#define USE_FLASH_DESCRIPTORS
//		#define USE_EEPROM_DESCRIPTORS
//		#define NO_INTERNAL_SERIAL
		#define FIXED_CONTROL_ENDPOINT_SIZE      8
		#define DEVICE_STATE_AS_GPIOR            0
		#define FIXED_NUM_CONFIGURATIONS         1
//		#define CONTROL_ONLY_DEVICE
		#define INTERRUPT_CONTROL_ENDPOINT
//		#define NO_DEVICE_REMOTE_WAKEUP
//		#define NO_DEVICE_SELF_POWER

		/* USB Host Mode Driver Related Tokens: */
//		#define HOST_STATE_AS_GPIOR              0
//		#define USB_HOST_TIMEOUT_MS              {Insert Value Here}
//		#define HOST_DEVICE_SETTLE_DELAY_MS	     {Insert Value Here}
//		#define NO_AUTO_VBUS_MANAGEMENT
//		#define INVERTED_VBUS_ENABLE_LINE

	#else

//		#error Unsupported architecture for this LUFA configuration file.

	#endif
#endif

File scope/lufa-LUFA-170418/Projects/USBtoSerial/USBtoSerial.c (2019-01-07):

/*
             LUFA Library
     Copyright (C) Dean Camera, 2017.

  dean [at] fourwalledcubicle [dot] com
           www.lufa-lib.org
*/

/*
  Copyright 2017  Dean Camera (dean [at] fourwalledcubicle [dot] com)

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
  The author disclaims all warranties with regard to this
  software, including all implied warranties of merchantability
  and fitness.  In no event shall the author be liable for any
  special, indirect or consequential damages or any damages
  whatsoever resulting from loss of use, data or profits, whether
  in an action of contract, negligence or other tortious action,
  arising out of or in connection with the use or performance of
  this software.
*/

/** \file
 *
 *  Main source file for the USBtoSerial project. This file contains the main tasks of
 *  the project and is responsible for the initial application hardware configuration.
 */

#include "USBtoSerial.h"

/** Circular buffer to hold data from the host before it is sent to the device via the serial port. */
static RingBuffer_t USBtoUSART_Buffer;

/** Underlying data buffer for \ref USBtoUSART_Buffer, where the stored bytes are located. */
static uint8_t      USBtoUSART_Buffer_Data[128];

/** Circular buffer to hold data from the serial port before it is sent to the host. */
static RingBuffer_t USARTtoUSB_Buffer;

/** Underlying data buffer for \ref USARTtoUSB_Buffer, where the stored bytes are located. */
static uint8_t      USARTtoUSB_Buffer_Data[128];

/** LUFA CDC Class driver interface configuration and state information. This structure is
 *  passed to all CDC Class driver functions, so that multiple instances of the same class
 *  within a device can be differentiated from one another.
 */
USB_ClassInfo_CDC_Device_t VirtualSerial_CDC_Interface =
	{
		.Config =
			{
				.ControlInterfaceNumber         = INTERFACE_ID_CDC_CCI,
				.DataINEndpoint                 =
					{
						.Address                = CDC_TX_EPADDR,
						.Size                   = CDC_TXRX_EPSIZE,
						.Banks                  = 1,
					},
				.DataOUTEndpoint                =
					{
						.Address                = CDC_RX_EPADDR,
						.Size                   = CDC_TXRX_EPSIZE,
						.Banks                  = 1,
					},
				.NotificationEndpoint           =
					{
						.Address                = CDC_NOTIFICATION_EPADDR,
						.Size                   = CDC_NOTIFICATION_EPSIZE,
						.Banks                  = 1,
					},
			},
	};


/** Main program entry point. This routine contains the overall program flow, including initial
 *  setup of all components and the main program loop.
 */
//int main(void)
//{
//	SetupHardware();
//
//	RingBuffer_InitBuffer(&USBtoUSART_Buffer, USBtoUSART_Buffer_Data, sizeof(USBtoUSART_Buffer_Data));
//	RingBuffer_InitBuffer(&USARTtoUSB_Buffer, USARTtoUSB_Buffer_Data, sizeof(USARTtoUSB_Buffer_Data));
//
//	LEDs_SetAllLEDs(LEDMASK_USB_NOTREADY);
//	GlobalInterruptEnable();
//
//	for (;;)
//	{
//		/* Only try to read in bytes from the CDC interface if the transmit buffer is not full */
		if (!(RingBuffer_IsFull(&USBtoUSART_Buffer)))
		{
			int16_t ReceivedByte = CDC_Device_ReceiveByte(&VirtualSerial_CDC_Interface);

			/* Store received byte into the USART transmit buffer */
			if (!(ReceivedByte < 0))
			  RingBuffer_Insert(&USBtoUSART_Buffer, ReceivedByte);
		}

		uint16_t BufferCount = RingBuffer_GetCount(&USARTtoUSB_Buffer);
		if (BufferCount)
		{
			Endpoint_SelectEndpoint(VirtualSerial_CDC_Interface.Config.DataINEndpoint.Address);

			/* Check if a packet is already enqueued to the host - if so, we shouldn't try to send more data
			 * until it completes as there is a chance nothing is listening and a lengthy timeout could occur */
			if (Endpoint_IsINReady())
			{
				/* Never send more than one bank size less one byte to the host at a time, so that we don't block
				 * while a Zero Length Packet (ZLP) to terminate the transfer is sent if the host isn't listening */
				uint8_t BytesToSend = MIN(BufferCount, (CDC_TXRX_EPSIZE - 1));

				/* Read bytes from the USART receive buffer into the USB IN endpoint */
				while (BytesToSend--)
				{
					/* Try to send the next byte of data to the host, abort if there is an error without dequeuing */
					if (CDC_Device_SendByte(&VirtualSerial_CDC_Interface,
											RingBuffer_Peek(&USARTtoUSB_Buffer)) != ENDPOINT_READYWAIT_NoError)
					{
						break;
					}

					/* Dequeue the already sent byte from the buffer now we have confirmed that no transmission error occurred */
					RingBuffer_Remove(&USARTtoUSB_Buffer);
				}
			}
		}

		/* Load the next byte from the USART transmit buffer into the USART if transmit buffer space is available */
		if (Serial_IsSendReady() && !(RingBuffer_IsEmpty(&USBtoUSART_Buffer)))
		  Serial_SendByte(RingBuffer_Remove(&USBtoUSART_Buffer));

		CDC_Device_USBTask(&VirtualSerial_CDC_Interface);
		USB_USBTask();
	}
}

/** Configures the board hardware and chip peripherals for the demo's functionality. */
//void SetupHardware(void)
//{
//#if (ARCH == ARCH_AVR8)
//	/* Disable watchdog if enabled by bootloader/fuses */
//	MCUSR &= ~(1 << WDRF);
//	wdt_disable();
//
//	/* Disable clock division */
//	clock_prescale_set(clock_div_1);
//#endif
//
//	/* Hardware Initialization */
//	LEDs_Init();
//	USB_Init();
//}

/** Event handler for the library USB Connection event. */
void EVENT_USB_Device_Connect(void)
{
	LEDs_SetAllLEDs(LEDMASK_USB_ENUMERATING);
}

/** Event handler for the library USB Disconnection event. */
void EVENT_USB_Device_Disconnect(void)
{
	LEDs_SetAllLEDs(LEDMASK_USB_NOTREADY);
}

/** Event handler for the library USB Configuration Changed event. */
void EVENT_USB_Device_ConfigurationChanged(void)
{
	bool ConfigSuccess = true;

	ConfigSuccess &= CDC_Device_ConfigureEndpoints(&VirtualSerial_CDC_Interface);

	LEDs_SetAllLEDs(ConfigSuccess ? LEDMASK_USB_READY : LEDMASK_USB_ERROR);
}

/** Event handler for the library USB Control Request reception event. */
void EVENT_USB_Device_ControlRequest(void)
{
	CDC_Device_ProcessControlRequest(&VirtualSerial_CDC_Interface);
}

/** ISR to manage the reception of data from the serial port, placing received bytes into a circular buffer
 *  for later transmission to the host.
 */
//ISR(USART1_RX_vect, ISR_BLOCK)
//{
//	uint8_t ReceivedByte = UDR1;
//
//	if ((USB_DeviceState == DEVICE_STATE_Configured) && !(RingBuffer_IsFull(&USARTtoUSB_Buffer)))
//	  RingBuffer_Insert(&USARTtoUSB_Buffer, ReceivedByte);
//}
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

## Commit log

2019-01-07 Initial commit after the 35c3 workshops
    [BoardDeviceMap.cfg, BootloaderDeviceMap.cfg]
2019-03-16 add PCB, update README
    [xmegatest-B.Cu.gbr, xmegatest-B.Mask.gbr, xmegatest-B.Paste.gbr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]
2019-12-24 Fixed bit-rot: horrorscope not building Added a auto-feature for the gui
    [HorrorScope.c, gui.py]
